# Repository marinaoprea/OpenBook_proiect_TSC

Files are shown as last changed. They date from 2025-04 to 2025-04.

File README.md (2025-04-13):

### ESP32-C6 pin connections
* 3V3 - charging 3V3
* EN - Reset button
* IO0 - pin for communication with the RTC (to get alert or timing signals)
* IO1 - pin used to communicate with the RTC to get a stable clock reference
* IO2 - used for SPI (Master In Slave Out)
* IO3 - used to connect to display, indicates the display's busy status
* IO4 - used to communicate with the SD card
* IO5 - used to connect to the display, distinguishes between data and command signals sent to
        to the display
* IO6 - used for SPI communication, synchronizes data transfer
* IO7 - used for SPI (Master Out Slave In)
* IO8 - not used
* IO9 - Boot button
* IO10 - used to connect to the display, selects the display for communication
* IO11 - selects the flash memory for communication
* IO12 - D+ for USB connection
* IO13 - D- for USB connection
* IO15 - Change button
* TXd0 / GPIO16 - used for UART debugging
* RXD0/GPIO17 - used for UART debugging
* IO18 - resets RTC
* IO19 - power pin for I2C communication
* IO20 - power for display
* IO21 - used for I2C, data pin
* IO22 - used for I2C, clock pin
* IO23 - resets display
* GND - connected to GND

### Bill of Materials

| Part | Value | Datasheet Link | Buy Link
|:---|:---|:---|:---|
| BOOT_BUTTON | BUTTON_CUSYOMV1 | [Datasheet](https://www3.panasonic.biz/ac/e_download/control/switch/light-touch/catalog/sw_lt_eng_6s_th.pdf?f_cd=402892) | [Buy](https://ro.mouser.com/ProductDetail/Panasonic/EVQ-PUJ02K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)
| C1 | 100nF | [Datasheet](https://ro.mouser.com/datasheet/2/447/KEM_C1006_X5R_SMD-3316465.pdf) | [Buy](https://ro.mouser.com/ProductDetail/YAGEO/CC0402MRX5R5BB106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)
| C1_BAT | 4.7uF | [Datasheet](https://ro.mouser.com/datasheet/2/447/KEM_C1006_X5R_SMD-3316465.pdf) | [Buy](https://ro.mouser.com/ProductDetail/YAGEO/CC0402MRX5R5BB106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)
| C1_BAT1 | 4.7uF |  |
| C1_BAT2 | 4.7uF |  |
| C2 | 100nF |  |
| C2_BAT | 4.7uF |  |
| C3 | 100uF TANT |  |
| C4 | 4.7uF/25V |  |
| C4_USB | 100nF |  |
| C5 | 1uF |  |
| C5_USB | 4.7uF |  |
| C6 | 100nF |  |
| C7 | 10uF |  |
| C8 | 100nF |  |
| C9 | 100nF |  |
| C10 | 100nF |  |
| C10_SUPERCAP | | [Datasheet](https://www.snapeda.com/parts/CPH3225A/Seiko+Instruments/view-part/?ref=eda) | [Buy](https://www.digikey.ro/en/products/detail/seiko-instruments/CPH3225A/8692444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)
| CHANGE_BUTTON BUTTON_CUSYOMV1 | |  |
| CHG_LED | |[Datasheet](https://dammedia.osram.info/media/resource/hires/osram-dam-14795755/LG%20R971_EN.pdf) | [Buy](https://www.arrow.com/en/products/kp-1608surck/kingbright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)
| C_DELAY | 100nF |  |
| D1 | | [Datasheet](https://www.snapeda.com/parts/USBLC6-2SC6Y/STMicroelectronics/view-part/?ref=eda) | [Buy](https://www.digikey.ro/en/products/detail/stmicroelectronics/USBLC6-2SC6Y/2756523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)
| D2 |  |  |
| D3 |  | [Datasheet](https://www.snapeda.com/parts/MBR0530/Onsemi/view-part/?ref=eda) | [Buy](https://www.digikey.ro/en/products/detail/smc-diode-solutions/MBR0530/16692306)
| D4 | | [Datasheet](https://www.snapeda.com/parts/MBR0530/Onsemi/view-part/?ref=eda) |
| D5 |  | [Datasheet](https://www.snapeda.com/parts/MBR0530/Onsemi/view-part/?ref=eda) |
| D6 |  | [Datasheet](https://www.snapeda.com/parts/PGB1010603MR/Littelfuse/view-part/?ref=eda) |
| D7 |  |  |
| D8 |  | [Datasheet](https://www.snapeda.com/parts/PGB1010603MR/Littelfuse/view-part/?ref=eda) | [Buy](https://www.digikey.ro/en/products/detail/littelfuse-inc/PGB1010603MR/715755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)
| D9 || [Datasheet](https://www.snapeda.com/parts/PGB1010603MR/Littelfuse/view-part/?ref=eda) |
| D10 |  | [Datasheet](https://www.snapeda.com/parts/PGB1010603MR/Littelfuse/view-part/?ref=eda) |
| D11 |  | [Datasheet](https://www.snapeda.com/parts/PGB1010603MR/Littelfuse/view-part/?ref=eda) |
| D12 |  | [Datasheet](https://www.snapeda.com/parts/PGB1010603MR/Littelfuse/view-part/?ref=eda) |
| EPD_C1 | 1uF/50V | [Datasheet](https://ro.mouser.com/datasheet/2/396/TDK_4_24_2024_MAASU32NSB7105KTCA01_SS-3440852.pdf) |
| EPD_C2 | 1uF/50V |  |
| EPD_C5 | 1uF/50V |  |
| EPD_C6 | 1uF/50V |  |
| EPD_C7 | 1uF/50V |  |
| EPD_C8 | 1uF/50V |  |
| EPD_C9 | 1uF/50V |  |
| EPD_C10 | 1uF/50V |  |
| EPD_C11 | 1uF/50V |  |
| EPD_C12 | 1uF/50V |  |
| IC2 |  | [Datasheet](https://datasheet.datasheetarchive.com/originals/distributors/Datasheets_SAMA/f2b9741ef86007909f138d561a359946.pdf) | [Buy](https://www.digikey.ro/en/products/detail/rohm-semiconductor/BD5229G-TR/3663792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)
| IC4 | | [Datasheet](https://www.torexsemi.com/file/xc6220/XC6220.pdf) | [Buy](https://www.digikey.ro/en/products/detail/torex-semiconductor-ltd/XC6220A331MR-G/21780806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)
| J1 |  | [Datasheet](https://www.hirose.com/en/product/document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) | [Buy](https://www.digikey.ro/en/products/detail/hirose-electric-co-ltd/FH34SRJ-24S-0.5SH(99)/5156248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)
| J2 | | [Datasheet](https://gct.co/files/drawings/usb4110.pdf) | [Buy](https://ro.mouser.com/ProductDetail/GCT/USB4110-GF-A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.)
| J3 |  | [Datasheet](https://cdn-shop.adafruit.com/product-files/4208/4208_Kaweei_C13396_diagram.pdf) | [Buy](https://ro.mouser.com/ProductDetail/JST-Commercial/SM04B-SRSS-TBLFSN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)
| J4 | | [Datasheet](https://www.attend.com.tw/data/download/file/112A-TAAR-R03.pdf) | [Buy](https://www.digikey.ro/en/products/detail/attend-technology/112A-TAAR-R03/17633923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)
| L1 | 68uH | [Datasheet](https://ro.mouser.com/datasheet/2/390/CR75-514217.pdf) | [Buy](https://www.chip1stop.com/USA/en/products/Wurth-Electronics/744043680/WURT*0001522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)
| PFMF.050.1 | ESP32C6_VARISTORCN1812 | [Datasheet](www.farnell.com/datasheets/49238.pdf) | [Buy](https://ro.mouser.com/ProductDetail/EPCOS-TDK/B72520T0350K062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)
| Q1 | 20V/4.2A/52m?/1.4W | [Datasheet](https://www.diodes.com/assets/Datasheets/DMG2305UX.pdf) | [Buy](https://www.digikey.ro/en/products/detail/diodes-incorporated/DMG2305UX-7/4340666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)
| Q2 | 20V/4.2A/52m?/1.4W |  |
| R1 | 10K | [Datasheet](https://www.vishay.com/doc?20037) | [Buy](https://ro.mouser.com/ProductDetail/YAGEO/RC0402FR-07100KL?qs=mnq%2FyloZIXzTlUn7JAHSWg%3D%3D)|
| R1_BAT | 200 | [Datasheet](https://www.vishay.com/doc?60057) |
| R1_PINH | 10K |  |
| R1_PINH1 | 10K |  |
| R1_PWRUSB | 100K | [Datasheet](https://ro.mouser.com/datasheet/2/414/TTRB_S_A0010186342_1-2565648.pdf) |
| R2 | 2.2 |  |
| R2-PINH1 | 10K |  |
| R2-USB | 5k1 | [Datasheet](https://www.vishay.com/doc?20008) |
| R2-USB1 | 5k1 |  |
| R2_BAT | 2K |  |
| R2_PINH | 10K |  |
| R3 | 0.47 |  |
| R4 | 10K |  |
| R5 | 10K |  |
| R6 | 10K |  |
| R7 | 10K |  |
| R8 | 10K |  |
| R9 | 10K |  |
| R10 | 10K |  |
| RESET_BUTTON | BUTT |  |
| R_BOOT | 10K |  |
| R_CAPACITOR | 15 |  |
| R_CHANGE | 10K |  |
| R_CL1 | 10K |  |
| R_RESET | 10K |  |
| SJ1 | |  |
| U1 | | [Datasheet](https://www.snapeda.com/parts/ESP32-C6-WROOM-1-N8/Espressif+Systems/view-part/?ref=eda) | [Buy](https://www.digikey.ro/en/products/detail/espressif-systems/ESP32-C6-WROOM-1-N8/17728866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)
| U2 |  | [Datasheet](https://ro.mouser.com/datasheet/2/268/MCP73831_Family_Data_Sheet_DS20001984H-3441711.pdf) | [Buy](https://ro.mouser.com/ProductDetail/Microchip-Technology/MCP73831T-2ACI-OT?qs=yUQqVecv4qvbBQBGbHx0Mw%3D%3D)
| U3 | | [Datasheet](https://ro.mouser.com/datasheet/2/609/DS3231-3421123.pdf) | [Buy](https://www.digikey.ro/en/products/detail/analog-devices-inc-maxim-integrated/DS3231SN/1197576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)
| U4 | | [Datasheet](https://www.snapeda.com/parts/MAX17048G+T10/Analog+Devices/view-part/?ref=eda) | [Buy](https://www.digikey.ro/en/products/detail/analog-devices-inc-maxim-integrated/MAX17048G-T10/3758921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)
| U5 |  | [Datasheet](https://www.snapeda.com/parts/W25Q512JVEIQ/Winbond+Electronics/view-part/?ref=eda) | [Buy](https://www.digikey.ro/en/products/detail/winbond-electronics/W25Q512JVEIQ/10244706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)
| U6 |  | [Datasheet](https://ro.mouser.com/datasheet/2/783/BST_BME680_DS001-1509608.pdf) | [Buy](https://www.digikey.ro/en/products/detail/bosch-sensortec/BME680/7401317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)

## Block diagram

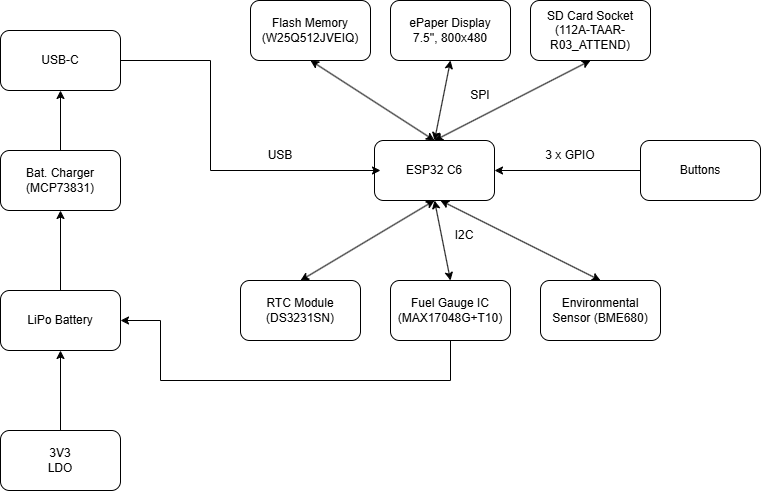
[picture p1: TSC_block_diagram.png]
Block diagram


## System Overview

This project integrates various components to create a versatile and efficient system with multiple functionalities.

## Components

### ESP32-C6-WROOM-1-N8 Microcontroller
- Serves as the central processing unit, managing all communication and control.
- Supports **Wi-Fi**, **Bluetooth**, **Zigbee**, and **Thread** for wireless communication.

### RTC Module (DS3231SN)
- Maintains accurate timekeeping and provides time/date information via the **I2C protocol**.

### Flash Memory (W25Q512JVEIQ)
- Provides high-speed storage using the **SPI protocol**
- Used for firmware and data storage

### Battery Management IC (MCP73831)
- Handles charging of the Li-Ion battery with input from the USB Type-C port.
- GPIO pins monitor charging status and control power management.

### Fuel Gauge IC (MAX17048G+T10)
- Tracks the battery's state of charge and communicates with the microcontroller using **I2C protocol**.

### Environmental Sensor (BME680)
- Monitors temperature, humidity, pressure, and gas levels.
- Connects via the **I2C protocol**.

### ePaper Display
- Displays information to the user.
- Interfaced using the **SPI protocol** for fast data updates.

### SD Card Socket (J4)
- Provides expandable storage for data logging or firmware updates.
- Communicates using the **SPI protocol**.

### USB Type-C Port (J2)
- Supplies power to the system and enables communication with external devices.
- Includes **D+** and **D−** lines for USB data transfer.

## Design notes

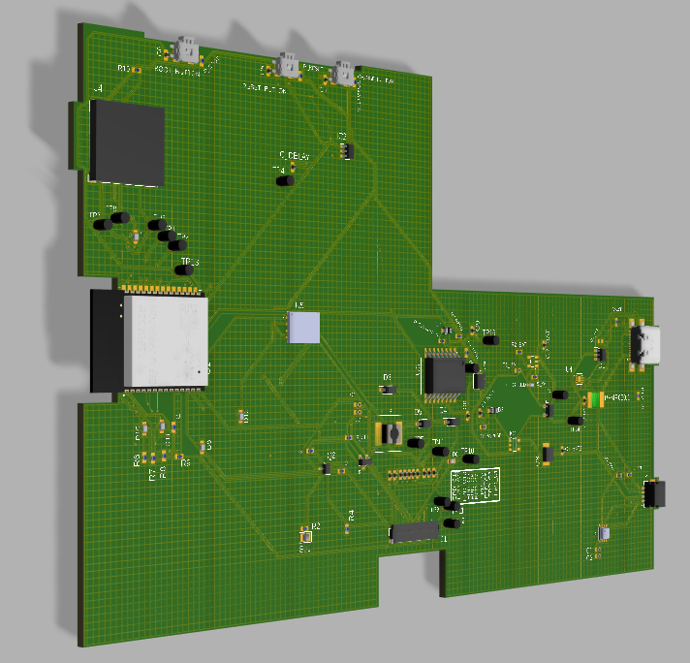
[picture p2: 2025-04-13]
Images/board_left_view.png

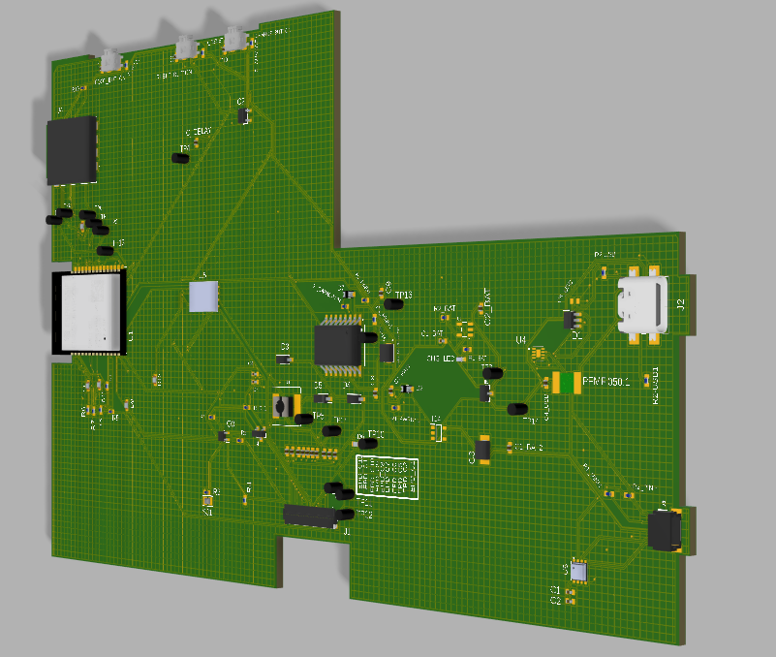
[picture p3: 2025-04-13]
Images/board_right_view.png

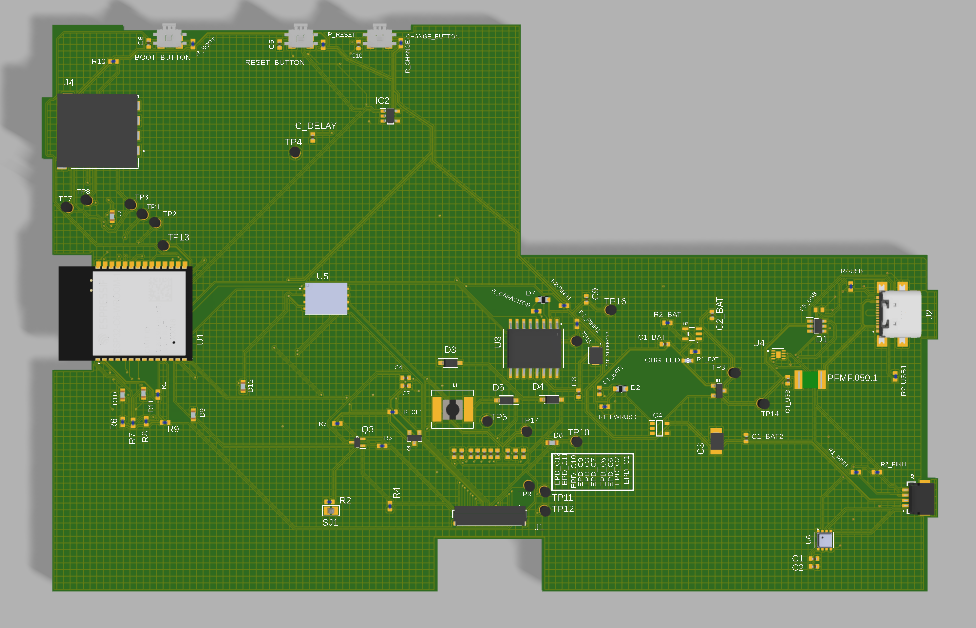
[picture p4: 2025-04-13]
Images/board_top_view.png

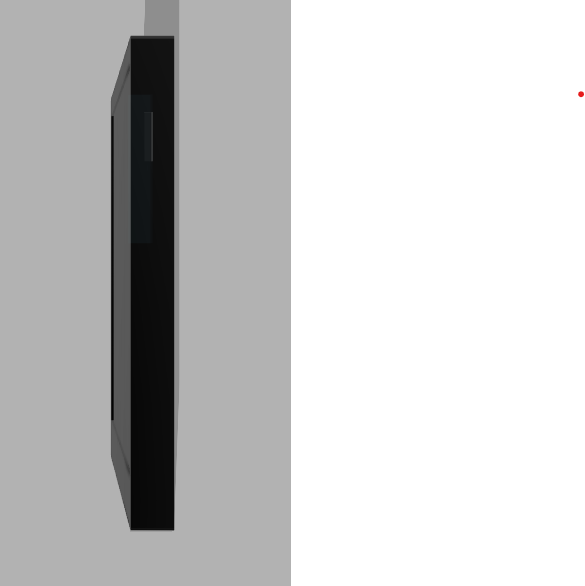
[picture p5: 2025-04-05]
Images/OpenBook_back_view.png

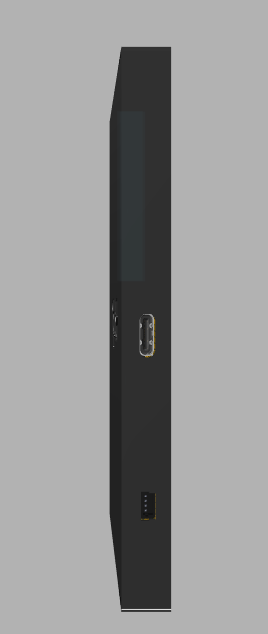
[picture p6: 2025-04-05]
Images/OpenBook_front_view.png

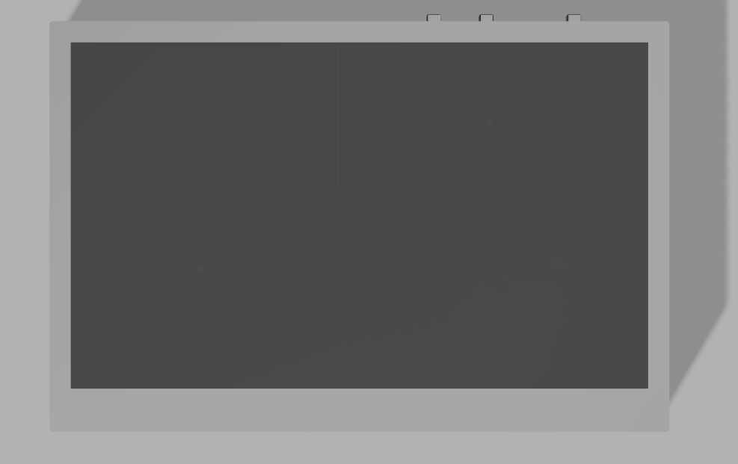
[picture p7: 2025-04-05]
Images/OpenBook_top_view.png

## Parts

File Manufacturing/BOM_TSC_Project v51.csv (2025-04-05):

Qty | Value | Device | Package | Parts | Description | ARROW_PART_NUMBER | ARROW_PRICE-STOCK | AVAILABILITY | CENTROID_NOT_SPECIFIED | CHECK_PRICES | DATASHEET | DESCRIPTION | DIGIKEY_DESCRIPTION | DIGIKEY_PART_NUMBER | HEIGHT | LEAD_FREE | MANUFACTURER_NAME | MANUFACTURER_PART_NUMBER | MF | MOUSER_PART_NUMBER | MOUSER_PRICE-STOCK | MOUSER_TESTING_PART_NUMBER | MOUSER_TESTING_PRICE-STOCK | MP | MPN | PACKAGE | POPULARITY | PREFIX | PRICE | PROD_ID | PURCHASE-URL | ROHS | SNAPEDA_LINK | SPICEMODEL | SPICEPREFIX | TEMPERATURE_RANGE_HIGH | TEMPERATURE_RANGE_LOW | TP_SIGNAL_NAME | VALUE
1 |  | ADAFRUIT_LEDCHIP-LED0603 | ADAFRUIT_CHIP-LED0603 | CHG_LED | LED
1 |  | SJ | SJ | SJ1 | SMD solder JUMPER |  |  |  |  |  |  |  |  |  |  |  |  |  |  |  |  |  |  |  |  |  | 3
1 | 0.47 | ESP32_WROVER_EAGLE-LTSPICE_RR0402 | ESP32_WROVER_EAGLE-LTSPICE_R0402 | R3 | RESISTOR, European symbol |  |  |  |  |  |  |  |  |  |  |  |  |  |  |  |  |  |  |  |  |  |  |  |  |  |  |  |  | NONE | R
1 | 100K | ESP32_WROVER_EAGLE-LTSPICE_RR0402 | ESP32_WROVER_EAGLE-LTSPICE_R0402 | R1_PWRUSB | RESISTOR, European symbol |  |  |  |  |  |  |  |  |  |  |  |  |  |  |  |  |  |  |  |  |  |  |  |  |  |  |  |  | NONE | R
2 | 100nF | EAGLE-LTSPICE_CC0402 | ESP32_WROVER_EAGLE-LTSPICE_C0402 | C4_USB, C_DELAY | CAPACITOR, European symbol |  |  |  |  |  |  |  |  |  |  |  |  |  |  |  |  |  |  |  |  |  |  |  |  |  |  |  |  | NONE | C
6 | 100nF | ESP32_WROVER_EAGLE-LTSPICE_CC0402 | ESP32_WROVER_EAGLE-LTSPICE_C0402 | C1, C2, C6, C8, C9, C10 | CAPACITOR, European symbol |  |  |  |  |  |  |  |  |  |  |  |  |  |  |  |  |  |  |  |  |  |  |  |  |  |  |  |  | NONE | C
1 | 100uF TANT | RCL_CPOL-EUCT3528 | RCL_CT3528 | C3 | POLARIZED CAPACITOR, European symbol |  |  |  |  |  |  |  |  |  |  |  |  |  |  |  |  |  |  |  |  |  | 0 |  |  |  |  |  |  |  | C
16 | 10K | ESP32_WROVER_EAGLE-LTSPICE_RR0402 | ESP32_WROVER_EAGLE-LTSPICE_R0402 | R1, R1_PINH, R1_PINH1, R2-PINH1, R2_PINH, R4, R5, R6, R7, R8, R9, R10, R_BOOT, R_CHANGE, R_CL1, R_RESET | RESISTOR, European symbol |  |  |  |  |  |  |  |  |  |  |  |  |  |  |  |  |  |  |  |  |  |  |  |  |  |  |  |  | NONE | R
1 | 10uF | ESP32_WROVER_EAGLE-LTSPICE_CC0402 | ESP32_WROVER_EAGLE-LTSPICE_C0402 | C7 | CAPACITOR, European symbol |  |  |  |  |  |  |  |  |  |  |  |  |  |  |  |  |  |  |  |  |  |  |  |  |  |  |  |  | NONE | C
1 | 112A-TAAR-R03_ATTEND | 112A-TAAR-R03_ATTEND | 112ATAARR03ATTEND | J4 | Micro SD Card Socket, Push-Push Type, Top Mount, SMT, H=1.83mm, 10u |  |  |  |  |  |  | Micro SD Card Socket | Push-Push Type | Top Mount | SMT | H=1.83mm | 10u |  |  | 1.9mm |  | ATTEND | 112A-TAAR-R03 ATTEND
1 | 15 | ESP32_WROVER_EAGLE-LTSPICE_RR0402 | ESP32_WROVER_EAGLE-LTSPICE_R0402 | R_CAPACITOR | RESISTOR, European symbol |  |  |  |  |  |  |  |  |  |  |  |  |  |  |  |  |  |  |  |  |  |  |  |  |  |  |  |  | NONE | R
1 | 1uF | ESP32_WROVER_EAGLE-LTSPICE_CC0402 | ESP32_WROVER_EAGLE-LTSPICE_C0402 | C5 | CAPACITOR, European symbol |  |  |  |  |  |  |  |  |  |  |  |  |  |  |  |  |  |  |  |  |  |  |  |  |  |  |  |  | NONE | C
10 | 1uF/50V | ESP32_WROVER_EAGLE-LTSPICE_CC0402 | ESP32_WROVER_EAGLE-LTSPICE_C0402 | EPD_C1, EPD_C2, EPD_C5, EPD_C6, EPD_C7, EPD_C8, EPD_C9, EPD_C10, EPD_C11, EPD_C12 | CAPACITOR, European symbol |  |  |  |  |  |  |  |  |  |  |  |  |  |  |  |  |  |  |  |  |  |  |  |  |  |  |  |  | NONE | C
1 | 2.2 | ESP32_WROVER_EAGLE-LTSPICE_RR0402 | ESP32_WROVER_EAGLE-LTSPICE_R0402 | R2 | RESISTOR, European symbol |  |  |  |  |  |  |  |  |  |  |  |  |  |  |  |  |  |  |  |  |  |  |  |  |  |  |  |  | NONE | R
1 | 200 | ESP32_WROVER_EAGLE-LTSPICE_RR0402 | ESP32_WROVER_EAGLE-LTSPICE_R0402 | R1_BAT | RESISTOR, European symbol |  |  |  |  |  |  |  |  |  |  |  |  |  |  |  |  |  |  |  |  |  |  |  |  |  |  |  |  | NONE | R
2 | 20V/4.2A/52m?/1.4W | ESP32_WROVER_SPARKFUN-DISCRETESEMI_MOSFET_PCH-DMG2305UX-7 | ESP32_WROVER_SPARKFUN-DISCRETESEMI_SOT23-3 | Q1, Q2 | P-channel MOSFETs |  |  |  |  |  |  |  |  |  |  |  |  |  |  |  |  |  |  |  |  |  |  |  |  | TRAN-14388 |  |  |  |  |  |  |  |  | 20V/4.2A/52m?/1.4W
1 | 2K | ESP32_WROVER_EAGLE-LTSPICE_RR0402 | ESP32_WROVER_EAGLE-LTSPICE_R0402 | R2_BAT | RESISTOR, European symbol |  |  |  |  |  |  |  |  |  |  |  |  |  |  |  |  |  |  |  |  |  |  |  |  |  |  |  |  | NONE | R
3 | 4.7uF | EAGLE-LTSPICE_CC0402 | ESP32_WROVER_EAGLE-LTSPICE_C0402 | C1_BAT1, C1_BAT2, C5_USB | CAPACITOR, European symbol |  |  |  |  |  |  |  |  |  |  |  |  |  |  |  |  |  |  |  |  |  |  |  |  |  |  |  |  | NONE | C
2 | 4.7uF | ESP32_WROVER_EAGLE-LTSPICE_CC0402 | ESP32_WROVER_EAGLE-LTSPICE_C0402 | C1_BAT, C2_BAT | CAPACITOR, European symbol |  |  |  |  |  |  |  |  |  |  |  |  |  |  |  |  |  |  |  |  |  |  |  |  |  |  |  |  | NONE | C
1 | 4.7uF/25V | ESP32_WROVER_EAGLE-LTSPICE_CC0402 | ESP32_WROVER_EAGLE-LTSPICE_C0402 | C4 | CAPACITOR, European symbol |  |  |  |  |  |  |  |  |  |  |  |  |  |  |  |  |  |  |  |  |  |  |  |  |  |  |  |  | NONE | C
2 | 5k1 | ESP32_WROVER_EAGLE-LTSPICE_RR0402 | ESP32_WROVER_EAGLE-LTSPICE_R0402 | R2-USB, R2-USB1 | RESISTOR, European symbol |  |  |  |  |  |  |  |  |  |  |  |  |  |  |  |  |  |  |  |  |  |  |  |  |  |  |  |  | NONE | R
1 | 68uH | INDUCTOR-CR75-68UH | CR75 | L1 | Inductors |  |  |  |  |  |  |  |  |  |  |  |  |  |  |  |  |  |  |  |  |  |  |  |  | NDUC-09739 |  |  |  |  |  |  |  |  | 68µH/±20%/1.05A
1 | BD5229G-TR | BD5229G-TR | SOT95P280X125-5N | IC2 | Voltage Detector with Adjustable Delay Time: CMOS processes are utilized to develop high precision, low current consumption CMOS reset ICs that allow arbitrary setting of the delay time. The extensive lineup includes both Nch Open Drain and CMOS output types in a wide range of detection voltages (from 2.3V to 6.0V, in 0.1V steps), enabling selection of the ideal solution based on customer requirements. In addition, the entire series is of course both lead-free and RoHS-compliant. |  |  |  |  |  |  | Voltage Detector with Adjustable Delay Time: CMOS processes are utilized to develop high precision | low current consumption CMOS reset ICs that allow arbitrary setting of the delay time. The extensive lineup includes both Nch Open Drain and CMOS output types in a wide range of detection voltages (from 2.3V to 6.0V | in 0.1V steps) | enabling selection of the ideal solution based on customer requirements. In addition | the entire series is of course both lead-free and RoHS-compliant. |  |  | 1.25mm |  | ROHM Semiconductor | BD5229G-TR |  | 755-BD5229G-TR | https://www.mouser.co.uk/ProductDetail/ROHM-Semiconductor/BD5229G-TR?qs=4kLU8WoGk0vvnhrrYwdszw%3D%3D
3 | BUTTON_CUSYOMV1 | BUTTON_CUSYOMV1 | MYBUTTON | BOOT_BUTTON, CHANGE_BUTTON, RESET_BUTTON
1 | CPH3225A | CPH3225A | CAPCP3225X100N | C10_SUPERCAP | Cap 0.011F 3.3V 1210 Flat Check availability |  |  | Not in stock |  | https://www.snapeda.com/parts/CPH3225A/Seiko+Instruments/view-part/?ref=eda |  | 11 mF (EDLC) Supercapacitor 3.3 V 1210 (3225 Metric) - - |  |  |  |  |  |  | Seiko Instruments |  |  |  |  | CPH3225A |  | 1210 Seiko |  |  | None |  | https://www.snapeda.com/api/url_track_click_mouser/?unipart_id=562593&manufacturer=Seiko Instruments&part_name=CPH3225A&search_term=None |  | https://www.snapeda.com/parts/CPH3225A/Seiko+Instruments/view-part/?ref=snap
1 | DS3231SN# | DS3231SN# | SOIC127P1032X265-16N | U3 | Real Time Clock Serial 16-Pin SOIC W T/R Check availability |  |  | In Stock |  | https://www.snapeda.com/parts/DS3231SN%23/Analog+Devices/view-part/?ref=eda |  | Extremely Accurate I2C-Integrated RTC/TCXO/Crystal |  |  |  |  |  |  | Analog Devices |  |  |  |  | DS3231SN# |  | SOIC-16 Maxim |  |  | None |  | https://www.snapeda.com/api/url_track_click_mouser/?unipart_id=99048&manufacturer=Analog Devices&part_name=DS3231SN#&search_term=None |  | https://www.snapeda.com/parts/DS3231SN%23/Analog+Devices/view-part/?ref=snap
1 | ESP32-C6-WROOM-1-N8 | ESP32-C6-WROOM-1-N8 | XCVR_ESP32-C6-WROOM-1-N8 | U1 | Check availability |  |  | In Stock |  | https://www.snapeda.com/parts/ESP32-C6-WROOM-1-N8/Espressif+Systems/view-part/?ref=eda |  | Multiprotocol Modules ESP32-C6 module | Wi-Fi 6 in 2.4 GHz band | Bluetooth 5 | Zigbee 3.0 and Thread. ESP34-WROOM Compatible - ENGINEERING SAMPLE |  |  |  |  |  |  | Espressif Systems |  |  |  |  | ESP32-C6-WROOM-1-N8 |  | None |  |  | None |  |  |  | https://www.snapeda.com/parts/ESP32-C6-WROOM-1-N8/Espressif+Systems/view-part/?ref=snap
1 | ESP32C6_VARISTORCN1812 | ESP32C6_VARISTORCN1812 | ESP32C6_VARISTOR_CT/CN1812 | PFMF.050.1 | VARISTOR |  |  |  |  |  |  |  |  |  |  |  |  |  |  |  |  |  |  |  |  |  | 0
2 | ESP32_WROVER_AVX---SD0805S020S1R0_AVX_SD0805S020S1R0_0_0AVX_SD0805S020S1R0_0_0 | ESP32_WROVER_AVX---SD0805S020S1R0_AVX_SD0805S020S1R0_0_0AVX_SD0805S020S1R0_0_0 | ESP32_WROVER_AVX---SD0805S020S1R0_AVX_SD0805S020S1R0_0 | D2, D7 | Schottky Barrier Rectifier Diode |  |  |  | No |  | http://datasheets.avx.com/schottky.pdf |  | DIODE SCHOTTKY 20V 1A 0805 | 478-7800-1-ND |  | yes |  |  | AVX | 581-SD0805S020S1R0 |  |  |  |  |  | 0805 (2012 metric) |  | D |  |  |  | yes |  |  |  | +125°C | -55°C
1 | ESP32_WROVER_BME680_BME680 | ESP32_WROVER_BME680_BME680 | ESP32_WROVER_BME680_PSON80P300X300X100-8N | U6 | Integrated Environmental Unit |  |  | Unavailable |  |  |  | Integrated Environmental Unit |  |  |  |  |  |  | Bosch Sensortec |  |  |  |  | BME680 |  | LGA-8 Bosch Tools |  |  | None
1 | ESP32_WROVER_SPARKFUN-IC-POWER_MCP73831 | ESP32_WROVER_SPARKFUN-IC-POWER_MCP73831 | ESP32_WROVER_SPARKFUN-IC-POWER_SOT23-5 | U2 | MCP73831T Li-Ion, Li-Pol Controller |  |  |  |  |  |  |  |  |  |  |  |  |  |  |  |  |  |  |  |  |  |  |  |  | IC-09995
1 | FH34SRJ-24S-0.5SH_99_ | FH34SRJ-24S-0.5SH_99_ | FH34SRJ24S05SH99 | J1 | (0.50mm) Surface Mount, Right Angle |  |  |  |  |  |  | 24 Position FFC | FPC Connector Contacts | (0.50mm) Surface Mount | Right Angle |  |  | 1.1mm |  | Hirose | FH34SRJ-24S-0.5SH(99) |  | 798-FH34SRJ24S05SH99 | https://www.mouser.co.uk/ProductDetail/Hirose-Connector/FH34SRJ-24S-0.5SH99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
1 | MAX17048G+T10 | MAX17048G+T10 | SON50P200X200X80-9N | U4 | Check availability |  |  | In Stock |  | https://www.snapeda.com/parts/MAX17048G+T10/Analog+Devices/view-part/?ref=eda |  | 3µA 1-Cell/2-Cell Fuel Gauge with ModelGauge |  |  |  |  |  |  | Analog Devices |  |  |  |  | MAX17048G+T10 |  | TDFN-8 Maxim |  |  | None |  | https://www.snapeda.com/api/url_track_click_mouser/?unipart_id=329239&manufacturer=Analog Devices&part_name=MAX17048G+T10&search_term=None |  | https://www.snapeda.com/parts/MAX17048G+T10/Analog+Devices/view-part/?ref=snap
3 | MBR0530 | MBR0530 | SOD3716X135N | D3, D4, D5 | ON SEMICONDUCTOR - MBR0530 - DIODE, SCHOTTKY, 0.5A, 30V, SOD-123 |  |  | In Stock |  | https://www.snapeda.com/parts/MBR0530/Onsemi/view-part/?ref=eda |  | Diode Schottky 30 V 500mA Surface Mount SOD-123 |  |  |  |  |  |  | ON Semiconductor |  |  |  |  | MBR0530 |  | SOD-123-2 ON Semiconductor |  |  | None |  | https://www.snapeda.com/api/url_track_click_mouser/?unipart_id=179458&manufacturer=ON Semiconductor&part_name=MBR0530&search_term=None |  | https://www.snapeda.com/parts/MBR0530/Onsemi/view-part/?ref=snap
6 | PGB1010603MR | PGB1010603MR | DIOC1608X36N | D6, D8, D9, D10, D11, D12 | Check availability |  |  | In Stock |  | https://www.snapeda.com/parts/PGB1010603MR/Littelfuse/view-part/?ref=eda |  | 150V (Typ) Clamp - Ipp Tvs Diode Surface Mount 0603 (1608 Metric) |  |  |  |  |  |  | Littelfuse Inc. |  |  |  |  | PGB1010603MR |  | 0603 Littelfuse Inc. |  |  | None |  | https://www.snapeda.com/api/url_track_click_mouser/?unipart_id=5659453&manufacturer=Littelfuse Inc.&part_name=PGB1010603MR&search_term=None |  | https://www.snapeda.com/parts/PGB1010603MR/Littelfuse/view-part/?ref=snap
1 | QWIIC_RIGHT_ANGLE | QWIIC_CONNECTORJS-1MM | JST04_1MM_RA | J3 | SparkFun I2C Standard Qwiic Connector |  |  |  |  |  |  |  |  |  |  |  |  |  |  |  |  |  |  |  |  |  |  |  |  | CONN-13694 |  |  |  |  |  |  |  |  | QWIIC_RIGHT_ANGLE
1 | SAMACSYS_PARTS_USB4110-GF-A | SAMACSYS_PARTS_USB4110-GF-A | SAMACSYS_PARTS_USB4110GFA | J2 | CONN USB 2.0 TYPE-C R/A SMT |  |  |  |  |  |  | CONN USB 2.0 TYPE-C R/A SMT |  |  | 3.26mm |  | GCT (GLOBAL CONNECTOR TECHNOLOGY) | USB4110-GF-A |  | 640-USB4110-GF-A | https://www.mouser.co.uk/ProductDetail/GCT/USB4110-GF-A?qs=KUoIvG%2F9IlYiZvIXQjyJeA%3D%3D
1 | SI1308EDL-T1-GE3 | SI1308EDL-T1-GE3 | SOT65P210X110-3N | Q3 | MOSFET N-Ch 30V 1.5A TrenchFET SC70 Vishay Si1308EDL-T1-GE3 N-channel MOSFET Transistor, 1.5 A, 30 V, 3-Pin SC-70 |  |  | In Stock |  | https://www.snapeda.com/parts/SI1308EDL-T1-GE3/Vishay+Siliconix/view-part/?ref=eda |  | Si1308EDL-T1-GE3 N-channel MOSFET Transistor | 1.5 A | 30 V | 3-Pin SC-70 | Siliconix / Vishay SI1308EDL-T1-GE3 |  |  |  |  |  |  | Vishay Siliconix |  |  |  |  | SI1308EDL-T1-GE3 |  | SOT-323 Vishay Semiconductor |  |  | None |  | https://www.snapeda.com/api/url_track_click_mouser/?unipart_id=274603&manufacturer=Vishay Siliconix&part_name=SI1308EDL-T1-GE3&search_term=None |  | https://www.snapeda.com/parts/SI1308EDL-T1-GE3/Vishay+Siliconix/view-part/?ref=snap
17 | TPTP20R | TPTP20R | TP20R | TP1, TP2, TP3, TP4, TP5, TP6, TP7, TP8, TP9, TP10, TP11, TP12, TP13, TP14, TP15, TP16, TP17 | Test pad |  |  |  |  |  |  |  |  |  |  |  |  |  |  |  |  |  |  |  |  |  | 2
1 | USBLC6-2SC6Y | USBLC6-2SC6Y | SOT95P280X145-6N | D1 | Low Cap. ESD Protection Auto SOT-23-6 STMicroelectronics USBLC6-2SC6Y, Dual Uni-Directional TVS Diode Array, 6-Pin SOT-23 |  |  | In Stock |  | https://www.snapeda.com/parts/USBLC6-2SC6Y/STMicroelectronics/view-part/?ref=eda |  | 17V Clamp 5A (8/20µs) Ipp Tvs Diode Surface Mount SOT-23-6 |  |  |  |  |  |  | STMicroelectronics |  |  |  |  | USBLC6-2SC6Y |  | SOT-23-6 STMicroelectronics |  |  | None |  |  |  | https://www.snapeda.com/parts/USBLC6-2SC6Y/STMicroelectronics/view-part/?ref=snap
1 | W25Q512JVEIQ | W25Q512JVEIQ | SON127P600X800X80-9N | U5 | Check availability |  |  | In Stock |  | https://www.snapeda.com/parts/W25Q512JVEIQ/Winbond+Electronics/view-part/?ref=eda |  | FLASH - NOR Memory IC 512Mb (64M x 8) SPI - Quad I/O 133 MHz 8-WSON (8x6) |  |  |  |  |  |  | Winbond Electronics |  |  |  |  | W25Q512JVEIQ |  | Package |  |  | None |  |  |  | https://www.snapeda.com/parts/W25Q512JVEIQ/Winbond+Electronics/view-part/?ref=snap
1 | XC6220A331MR-G | XC6220A331MR-G | SOT95P280X120-5N | IC4 | LDO Voltage Regulators |  |  |  |  |  |  | LDO Voltage Regulators |  |  | 1.2mm |  | Torex | XC6220A331MR-G |  | 865-XC6220A331MR-G | https://www.mouser.co.uk/ProductDetail/Torex-Semiconductor/XC6220A331MR-G?qs=AsjdqWjXhJ8ZSWznL1J0gg%3D%3D

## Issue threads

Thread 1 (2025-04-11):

Problemă Schematic

armandursei, 2025-04-11:
Schematicul atașat conține unele aspecte ce pot fi îmbunătățite din punct de vedere al organizării vizuale. Oferirea unor clarificări vizuale suplimentare va spori accesibilitatea și ușurința de depanare.

Closed 2025-04-15.

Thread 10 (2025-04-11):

Lipsesc linkuri de achiziție în BOM

armandursei, 2025-04-11:
Tabelului BOM (Bill of Materials) din README îi lipsesc linkuri către locurile de achiziționare ale componentelor. Fără acestea, utilizatorii nu pot obține cu ușurință componentele necesare pentru construirea proiectului. Adaugă linkuri către furnizori, precum Mouser sau Digi-Key, pentru componentele din BOM.

Closed 2025-04-15.

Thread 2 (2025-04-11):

Lipsa liniilor de separare între compartimente

armandursei, 2025-04-11:
Schematicul nu conține linii de separare pentru a distinge clar diferitele compartimente ale sistemului precum SD Card, USB C connector & ESD protection, E-Paper Drive Circuit. O separare vizuală clară ajută la identificarea rapidă a blocurilor funcționale din design, îmbunătățind lizibilitatea și facilitând depanarea. Adaugă linii de contur pentru a grupa componentele asociate vizual.

Closed 2025-04-15.

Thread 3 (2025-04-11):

Probleme PCB

armandursei, 2025-04-11:
PCB-ul este afectat de mai multe probleme ce țin de organizarea vizuală și integritatea semnalelor. Toate aceste aspecte trebuie abordate pentru a îmbunătăți performanța și fiabilitatea PCB-ului.

Closed 2025-04-15.

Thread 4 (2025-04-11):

Suprapunerea numelor componentelor

armandursei, 2025-04-11:
Numele unor componente precum U5, BOOT_BUTTON, TP7 și TP8 se suprapun cu rutele de semnal. Suprapunerea textului și a traseelor poate cauza confuzie în timpul fabricării PCB-ului și poate duce la probleme de lizibilitate, mai ales atunci când se depanează sau se modifică designul. Repoziționează numele componentelor specificate pentru a evita suprapunerile cu traseele.
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

Closed 2025-04-15.

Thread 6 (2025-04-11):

Probleme la rutarea semnalelor

armandursei, 2025-04-11:
Semnalul SCL de lângă J3 are un unghi drept. Aceste unghiuri drepte pe traseele de semnal pot cauza probleme de integritate a semnalului, în special pentru semnalele de mare viteză sau sensibile. Folosește alt unghi în loc de unghiuri drepte pentru a ruta semnalul acesta pentru a asigura o mai bună integritate a lui.
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

Closed 2025-04-15.

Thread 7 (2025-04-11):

Discontinuitatea planului de GND

armandursei, 2025-04-11:
Planul de GND este discontinuu în anumite zone, ceea ce poate duce la zgomot și comportament instabil. Asigură-te că planul de GND este continuu pe întreg designul. Folosește vias acolo unde este necesar pentru a menține un plan de GND solid.

Closed 2025-04-15.

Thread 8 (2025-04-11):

Layer incorect pentru dimensiuni PCB

armandursei, 2025-04-11:
Dimensiunile conturului PCB sunt plasate pe layer-ul TOP care nu este ideal pentru astfel de informații. Informațiile despre contur ar trebui să fie pe straturi exterioare pentru claritate, astfel încât să fie ușor de identificat și revizuit în timpul fabricării. Mută dimensiunile conturului PCB-ului pe un alt layer potrivit pentru astfel de informații.

Closed 2025-04-15.

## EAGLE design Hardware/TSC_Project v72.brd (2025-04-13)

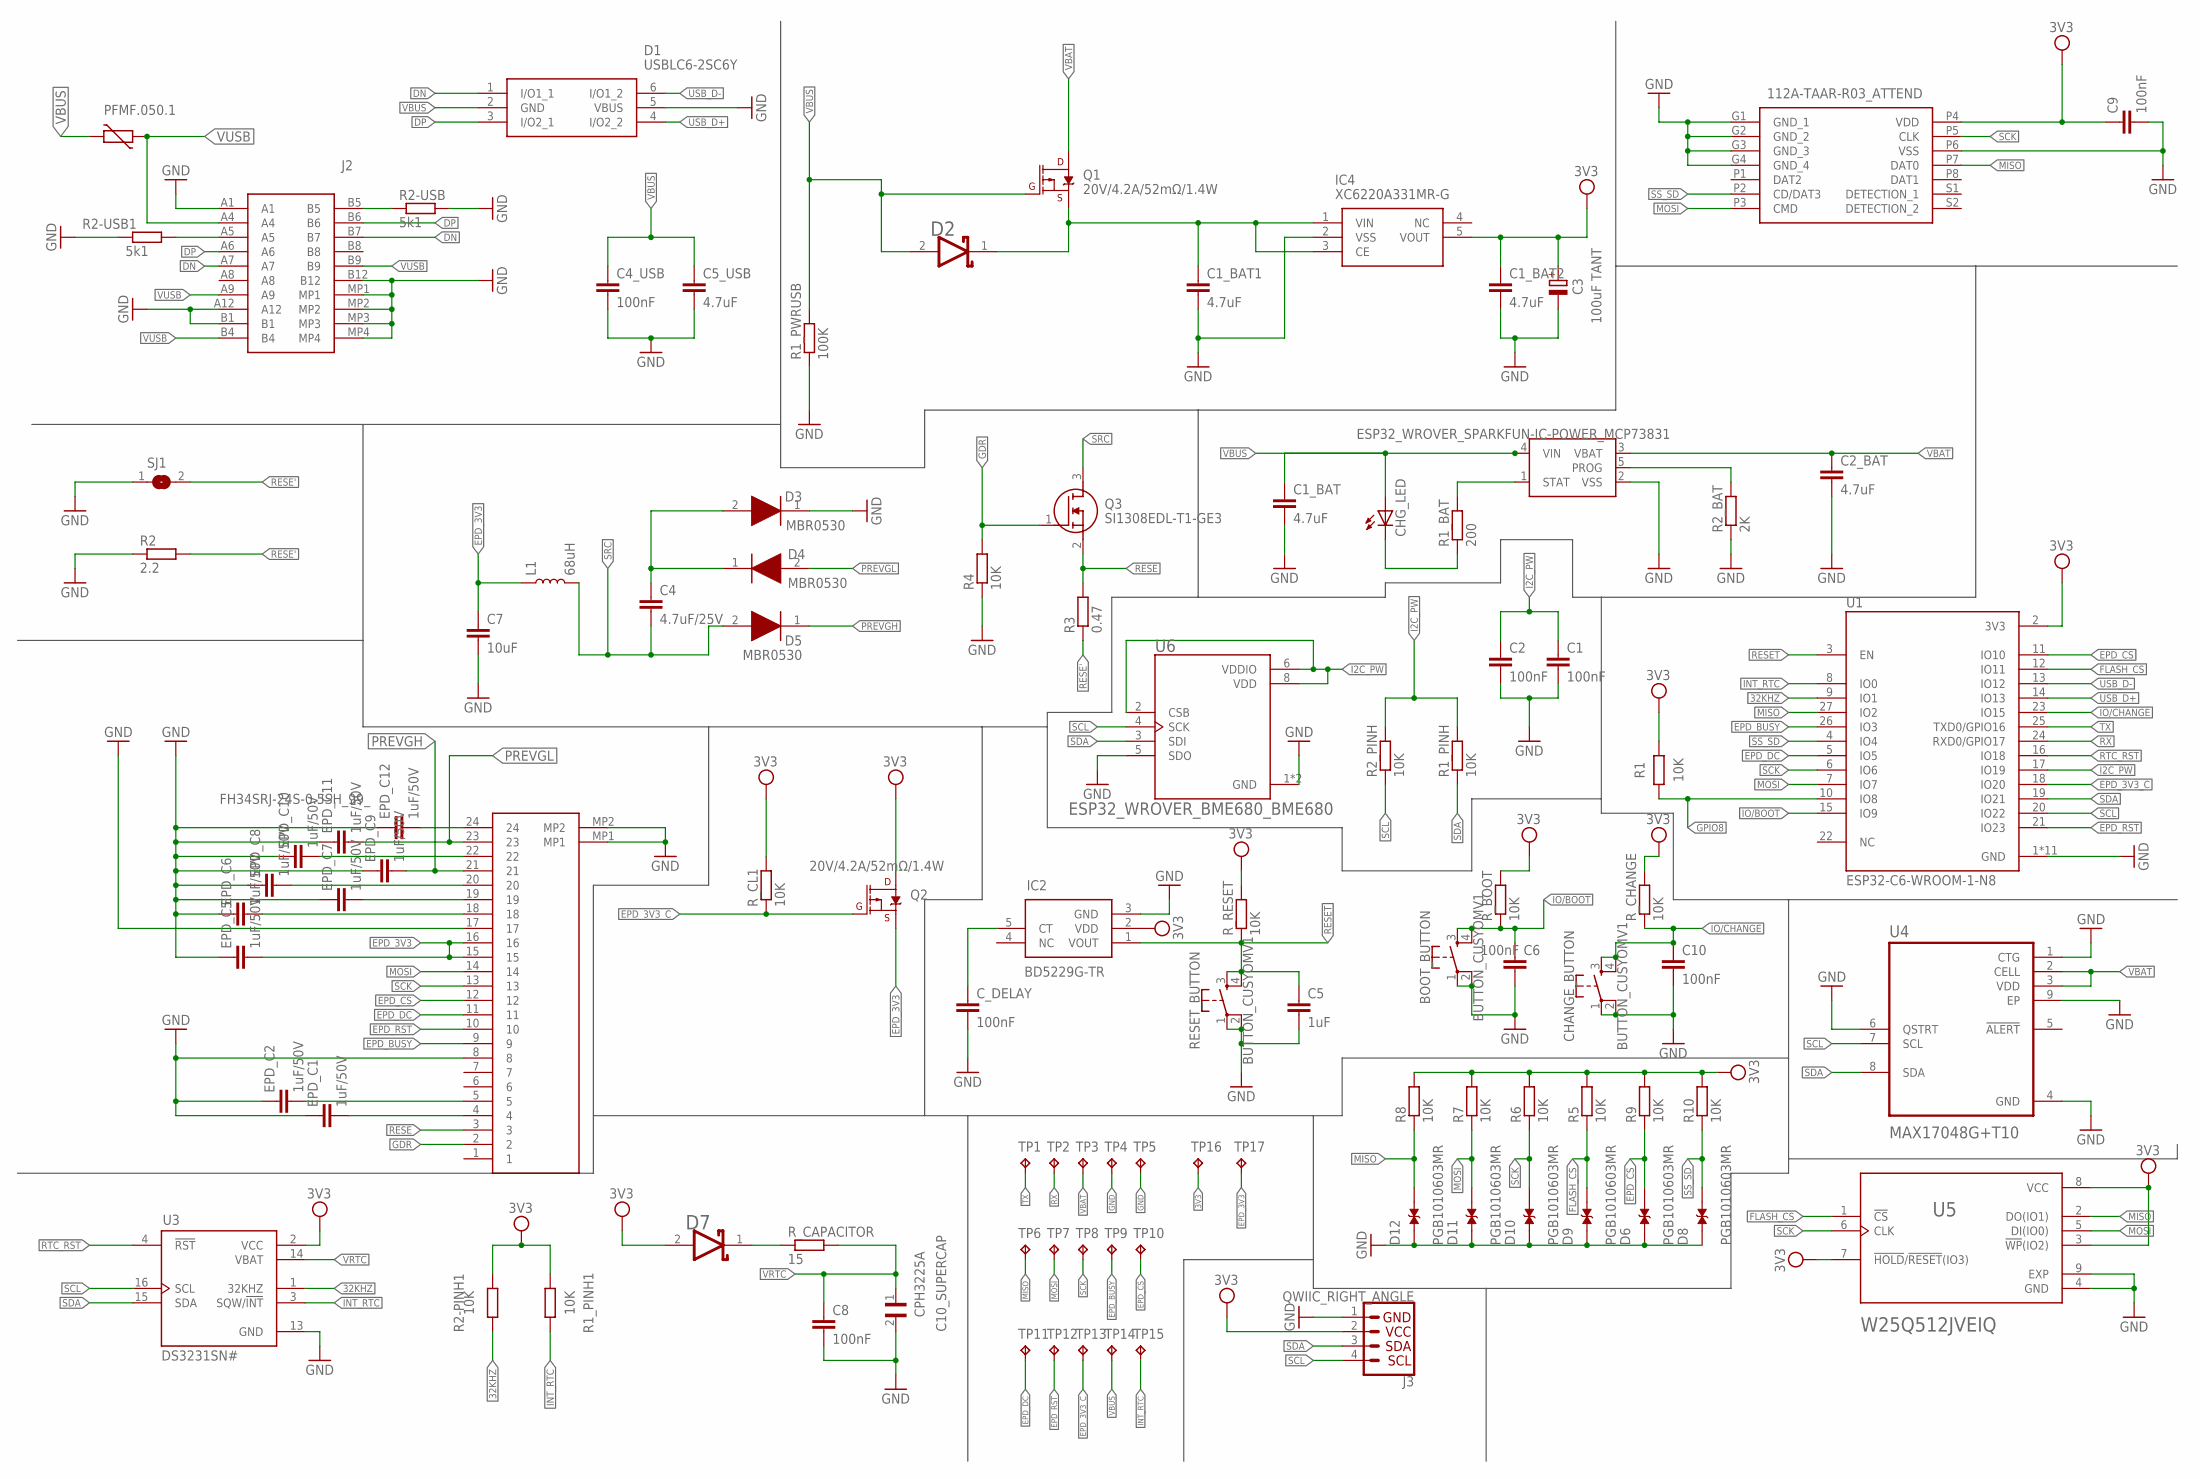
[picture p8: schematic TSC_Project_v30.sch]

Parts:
BOOT_BUTTON: BUTTON_CUSYOMV1; MYBUTTON
C1, C2, C4_USB, C6, C8, C9, C10: 100nF; ESP32_WROVER_EAGLE-LTSPICE_C0402
C1_BAT, C1_BAT1, C1_BAT2, C2_BAT, C5_USB: 4.7uF; ESP32_WROVER_EAGLE-LTSPICE_C0402
C3: 100uF TANT; RCL_CT3528
C4: 4.7uF/25V; ESP32_WROVER_EAGLE-LTSPICE_C0402
C5: 1uF; ESP32_WROVER_EAGLE-LTSPICE_C0402
C7: 10uF; ESP32_WROVER_EAGLE-LTSPICE_C0402
C10_SUPERCAP: CPH3225A; CAPCP3225X100N
CHANGE_BUTTON: BUTTON_CUSYOMV1; MYBUTTON
CHG_LED: ADAFRUIT_LEDCHIP-LED0603; ADAFRUIT_CHIP-LED0603
C_DELAY: 100nF; ESP32_WROVER_EAGLE-LTSPICE_C0402
D1: USBLC6-2SC6Y; SOT95P280X145-6N
D2, D7: ESP32_WROVER_AVX---SD0805S020S1R0_AVX_SD0805S020S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; ESP32_WROVER_AVX---SD0805S020S1R0_AVX_SD0805S020S1R0_0
D3, D4, D5: MBR0530; SOD3716X135N
D6, D8, D9, D10, D11, D12: PGB1010603MR; DIOC1608X36N
EPD_C1, EPD_C2, EPD_C5, EPD_C6, EPD_C7, EPD_C8, EPD_C9, EPD_C10, EPD_C11, EPD_C12: 1uF/50V; ESP32_WROVER_EAGLE-LTSPICE_C0402
IC2: BD5229G-TR; SOT95P280X125-5N
IC4: XC6220A331MR-G; SOT95P280X120-5N
J1: FH34SRJ-24S-0.5SH_99_; FH34SRJ24S05SH99
J2: SAMACSYS_PARTS_USB4110-GF-A; SAMACSYS_PARTS_USB4110GFA
J3: QWIIC_RIGHT_ANGLE; JST04_1MM_RA
J4: 112A-TAAR-R03_ATTEND; 112ATAARR03ATTEND
L1: 68uH; CR75
PFMF.050.1: ESP32C6_VARISTORCN1812; ESP32C6_VARISTOR_CT/CN1812
Q1, Q2: 20V/4.2A/52mΩ/1.4W; ESP32_WROVER_SPARKFUN-DISCRETESEMI_SOT23-3
Q3: SI1308EDL-T1-GE3; SOT65P210X110-3N
R1, R1_PINH, R1_PINH1, R2-PINH1, R2_PINH, R4, R5, R6, R7, R8, R9, R10: 10K; ESP32_WROVER_EAGLE-LTSPICE_R0402
R1_BAT: 200; ESP32_WROVER_EAGLE-LTSPICE_R0402
R1_PWRUSB: 100K; ESP32_WROVER_EAGLE-LTSPICE_R0402
R2: 2.2; ESP32_WROVER_EAGLE-LTSPICE_R0402
R2-USB, R2-USB1: 5k1; ESP32_WROVER_EAGLE-LTSPICE_R0402
R2_BAT: 2K; ESP32_WROVER_EAGLE-LTSPICE_R0402
R3: 0.47; ESP32_WROVER_EAGLE-LTSPICE_R0402
RESET_BUTTON: BUTTON_CUSYOMV1; MYBUTTON
R_BOOT: 10K; ESP32_WROVER_EAGLE-LTSPICE_R0402
R_CAPACITOR: 15; ESP32_WROVER_EAGLE-LTSPICE_R0402
R_CHANGE: 10K; ESP32_WROVER_EAGLE-LTSPICE_R0402
R_CL1: 10K; ESP32_WROVER_EAGLE-LTSPICE_R0402
R_RESET: 10K; ESP32_WROVER_EAGLE-LTSPICE_R0402
SJ1: SJ
TP1, TP2, TP3, TP4, TP5, TP6, TP7, TP8, TP9, TP10, TP11, TP12, TP13, TP14, TP15, TP16, TP17: TPTP20R; TP20R
U1: ESP32-C6-WROOM-1-N8; XCVR_ESP32-C6-WROOM-1-N8
U2: ESP32_WROVER_SPARKFUN-IC-POWER_MCP73831; ESP32_WROVER_SPARKFUN-IC-POWER_SOT23-5
U3: DS3231SN#; SOIC127P1032X265-16N
U4: MAX17048G+T10; SON50P200X200X80-9N
U5: W25Q512JVEIQ; SON127P600X800X80-9N
U6: ESP32_WROVER_BME680_BME680; ESP32_WROVER_BME680_PSON80P300X300X100-8N

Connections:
3V3: C1_BAT2.1, C3.+, C9.1, D7.2 (ANODE), IC2.2 (VDD), IC4.5 (VOUT), J3.2, J4.P4 (VDD), Q2.3 (D), R1.2, R1_PINH1.2, R2-PINH1.2, R5.2, R6.2, R7.2, R8.2, R9.2, R10.2, R_BOOT.2, R_CHANGE.2, R_CL1.2, R_RESET.2, TP16.TP, U1.2 (3V3), U3.2 (VCC), U5.3 (!WP!(IO2)), U5.7 (!HOLD!/!RESET!(IO3)), U5.8 (VCC)
32KHZ: R2-PINH1.1, U1.9 (IO1), U3.1 (32KHZ)
DN: D1.1 (I/O1_1), J2.A7, J2.B7
DP: D1.3 (I/O2_1), J2.A6, J2.B6
EPD_3V3: C7.1, EPD_C5.2, J1.15, J1.16, L1.P$1 (1), Q2.2 (S), TP17.TP
EPD_3V3_C: Q2.1 (G), R_CL1.1, TP13.TP, U1.18 (IO20)
EPD_BUSY: J1.9, TP9.TP, U1.26 (IO3)
EPD_CS: D6.2, J1.12, R9.1, TP10.TP, U1.11 (IO10)
EPD_DC: J1.11, TP11.TP, U1.5 (IO5)
EPD_RST: J1.10, TP12.TP, U1.21 (IO23)
FLASH_CS: D9.2, R5.1, U1.12 (IO11), U5.1 (!CS)
GDR: J1.2, Q3.1 (G), R4.2
GND: BOOT_BUTTON.1, BOOT_BUTTON.2, C1.2, C1_BAT.2, C1_BAT1.2, C1_BAT2.2, C2.2, C2_BAT.2, C3.-, C4_USB.2, C5.2, C5_USB.2, C6.2, C7.2, C8.2, C9.2, C10.2, C10_SUPERCAP.2, CHANGE_BUTTON.1, CHANGE_BUTTON.2, C_DELAY.2, D1.5 (VBUS), D3.1 (K), D6.1, D8.1, D9.1, D10.1, D11.1, D12.1, EPD_C1.1, EPD_C2.1, EPD_C5.1, EPD_C6.1, EPD_C7.1, EPD_C8.1, EPD_C9.1, EPD_C10.1, EPD_C11.1, EPD_C12.1, IC2.3 (GND), IC4.2 (VSS), J1.8, J1.17, J1.MP1, J1.MP2, J2.A1, J2.A12, J2.B1, J2.B12, J2.MP1, J2.MP2, J2.MP3, J2.MP4, J3.1, J4.G1 (GND_1), J4.G2 (GND_2), J4.G3 (GND_3), J4.G4 (GND_4), J4.P6 (VSS), R1_PWRUSB.1, R2.1, R2-USB.2, R2-USB1.1, R2_BAT.1, R4.1, RESET_BUTTON.1, RESET_BUTTON.2, SJ1.1, TP4.TP, TP5.TP, U1.1 (GND), U1.28 (GND), U1.29_1 (GND), U1.29_2 (GND), U1.29_3 (GND), U1.29_4 (GND), U1.29_5 (GND), U1.29_6 (GND), U1.29_7 (GND), U1.29_8 (GND), U1.29_9 (GND), U2.2 (VSS), U3.13 (GND), U4.1 (CTG), U4.4 (GND), U4.6 (QSTRT), U4.9 (EP), U5.4 (GND), U5.9 (EXP), U6.1 (GND), U6.5 (SDO), U6.7 (GND)
GPIO8: R1.1, U1.10 (IO8)
I2C_PW: C1.1, C2.1, R1_PINH.2, R2_PINH.2, U1.17 (IO19), U6.2 (CSB), U6.6 (VDDIO), U6.8 (VDD)
INT_RTC: R1_PINH1.1, TP15.TP, U1.8 (IO0), U3.3 (SQW/!INT)
IO/BOOT: BOOT_BUTTON.3, BOOT_BUTTON.4, C6.1, R_BOOT.1, U1.15 (IO9)
IO/CHANGE: C10.1, CHANGE_BUTTON.3, CHANGE_BUTTON.4, R_CHANGE.1, U1.23 (IO15)
MISO: D12.2, J4.P7 (DAT0), R8.1, TP6.TP, U1.27 (IO2), U5.2 (DO(IO1))
MOSI: D11.2, J1.14, J4.P3 (CMD), R7.1, TP7.TP, U1.7 (IO7), U5.5 (DI(IO0))
unnamed: EPD_C12.2, J1.24
unnamed: R1_BAT.2, U2.1 (STAT)
unnamed: CHG_LED.C, R1_BAT.1
unnamed: D7.1 (CATHODE), R_CAPACITOR.1
unnamed: J2.A5, R2-USB1.2
unnamed: J2.B5, R2-USB.1
unnamed: R2_BAT.2, U2.5 (PROG)
unnamed: EPD_C1.2, J1.4
unnamed: C1_BAT1.1, D2.1 (CATHODE), IC4.1 (VIN), IC4.3 (CE), Q1.2 (S)
unnamed: EPD_C2.2, J1.5
unnamed: C4.1, D3.2 (A), D4.1 (K)
unnamed: EPD_C6.2, J1.18
unnamed: EPD_C7.2, J1.19
unnamed: EPD_C8.2, J1.20
unnamed: C_DELAY.1, IC2.5 (CT)
unnamed: EPD_C10.2, J1.22
PREVGH: D5.1 (K), EPD_C9.2, J1.21
PREVGL: D4.2 (A), EPD_C11.2, J1.23
RESE: J1.3, Q3.2 (S), R3.2
RESE': R2.2, R3.1, SJ1.2
RESET: C5.1, IC2.1 (VOUT), RESET_BUTTON.3, RESET_BUTTON.4, R_RESET.1, U1.3 (EN)
RTC_RST: U1.16 (IO18), U3.4 (!RST)
RX: TP2.TP, U1.24 (RXD0/GPIO17)
SCK: D10.2, J1.13, J4.P5 (CLK), R6.1, TP8.TP, U1.6 (IO6), U5.6 (CLK)
SCL: J3.4, R2_PINH.1, U1.20 (IO22), U3.16 (SCL), U4.7 (SCL), U6.4 (SCK)
SDA: J3.3, R1_PINH.1, U1.19 (IO21), U3.15 (SDA), U4.8 (SDA), U6.3 (SDI)
SRC: C4.2, D5.2 (A), L1.P$2 (2), Q3.3 (D)
SS_SD: D8.2, J4.P2 (CD/DAT3), R10.1, U1.4 (IO4)
TX: TP1.TP, U1.25 (TXD0/GPIO16)
USB_D+: D1.4 (I/O2_2), U1.14 (IO13)
USB_D-: D1.6 (I/O1_2), U1.13 (IO12)
VBAT: C2_BAT.1, Q1.3 (D), TP3.TP, U2.3 (VBAT), U4.2 (CELL), U4.3 (VDD)
VBUS: C1_BAT.1, C4_USB.1, C5_USB.1, CHG_LED.A, D1.2 (GND), D2.2 (ANODE), PFMF.050.1.2, Q1.1 (G), R1_PWRUSB.2, TP14.TP, U2.4 (VIN)
VRTC: C8.1, C10_SUPERCAP.1, R_CAPACITOR.2, U3.14 (VBAT)
VUSB: J2.A4, J2.A9, J2.B4, J2.B9, PFMF.050.1.1

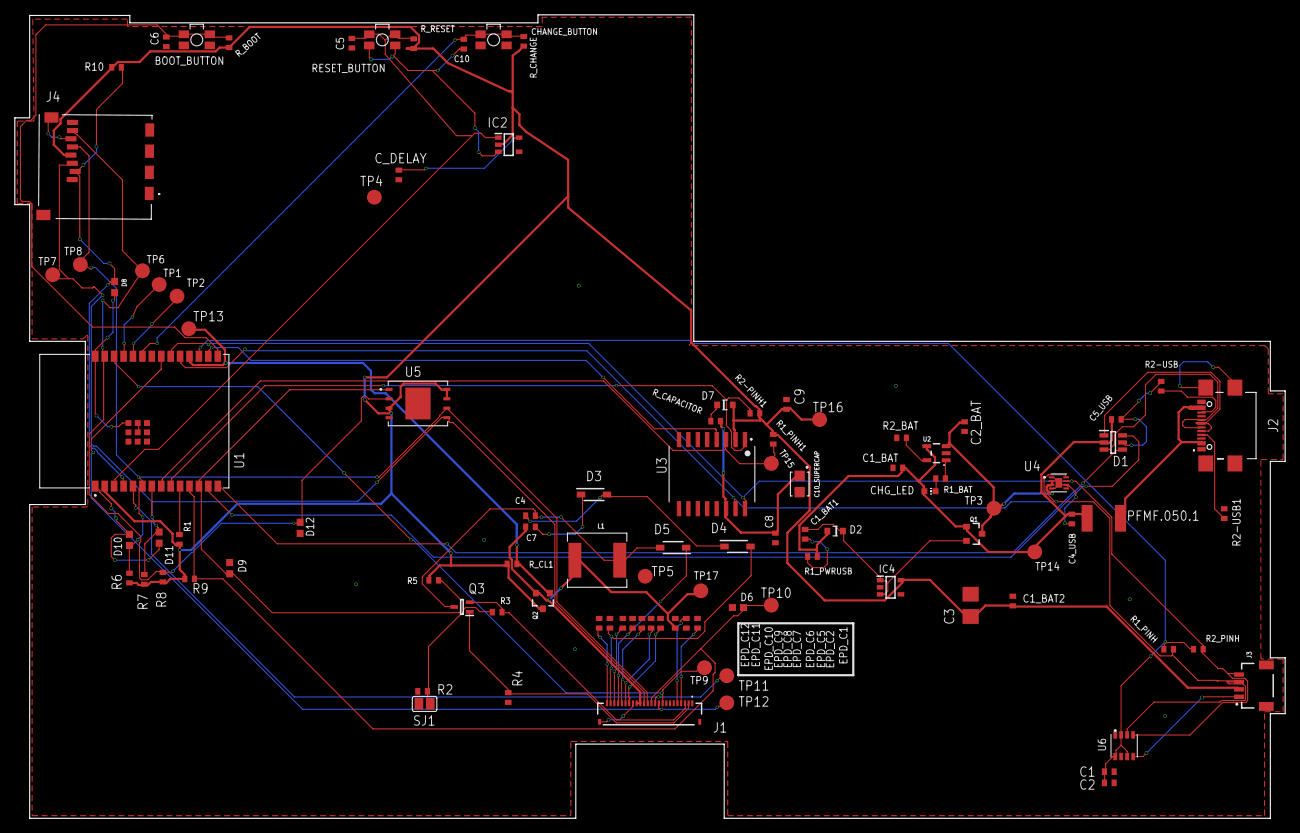
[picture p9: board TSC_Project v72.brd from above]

Board: 2 copper layers, 171.2 x 108.3 mm, 103 parts (0 on the bottom side), 55 nets.

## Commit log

2025-03-24 Added .sch and .brd
    [TSC_Project.brd, TSC_Project.sch]
2025-04-05 Added files .sch and .brd
    [TSC_Project v51.brd, TSC_Project_v29.sch]
2025-04-13 replaced board images
2025-04-13 replaced .sch and .brd
    [TSC_Project v72.brd, TSC_Project_v30.sch]
2025-04-15 updated f3z file
    [OpenBook.f3z]

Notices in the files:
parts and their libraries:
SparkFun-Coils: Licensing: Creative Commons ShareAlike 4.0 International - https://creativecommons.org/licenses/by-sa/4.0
